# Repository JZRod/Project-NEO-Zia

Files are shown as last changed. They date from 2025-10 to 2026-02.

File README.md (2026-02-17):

# Project NEO Zia
This circut board is intended to make the New Mexico Zia out of LED's 
There is a [PDF](assets/README.pdf) version of this doccument in the assets folder
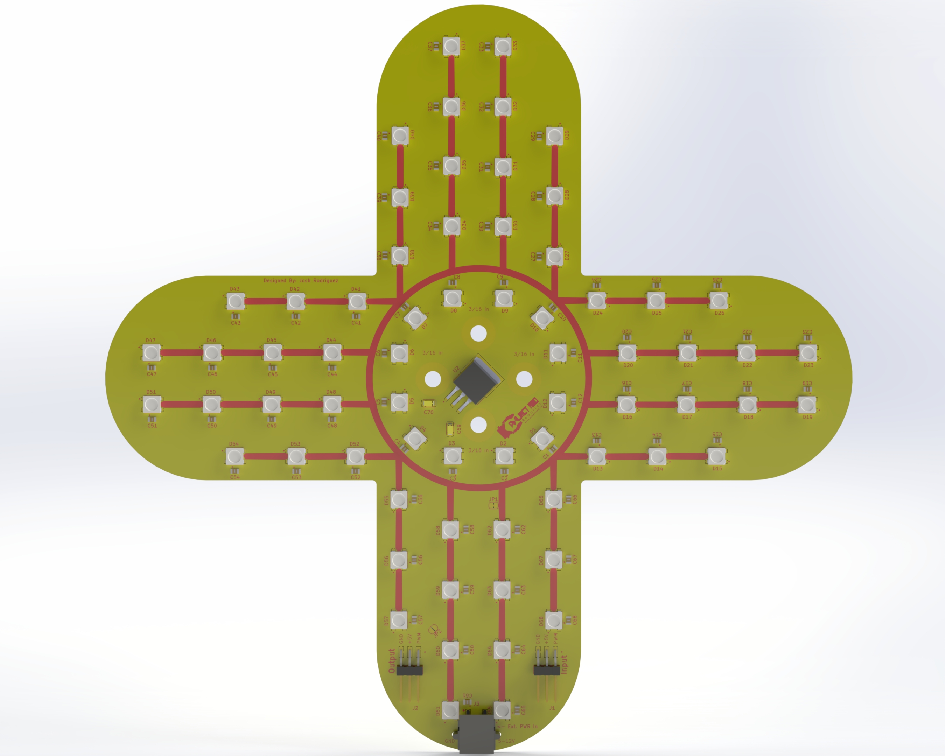
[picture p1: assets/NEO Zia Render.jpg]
ZIA PCB

## Using the board
This section goes over information on how to configure, wire, and mount the board. 
### Configuration
This PCB is designed to accept power from an external 12 volt input. It is also able to recieve power from a 5 volt PWM cable. By default the board is configured to recieve power from the 12 volt external power input.  
- For the PWM power input open JP1 and bridge JP2
- For external power input open JP2 and bridge JP1  
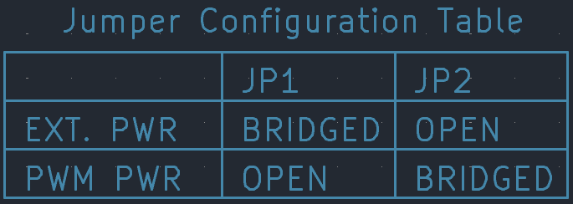
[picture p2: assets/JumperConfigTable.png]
configtable

> **NEVER BRIDGE BOTH JUMPERS AT ONCE**
### Wiring
#### External Power Input
The external power input can accept voltages between 5 and 12 volts. When using the external power input fuse it at a maximum of 5 amps.  
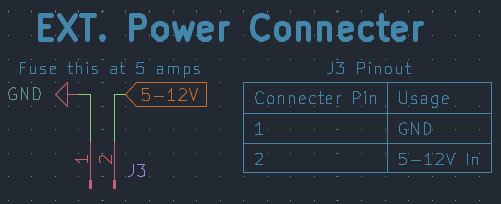
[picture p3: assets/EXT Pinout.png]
EXTPWRPINOUT

#### PWM Connections
There are two PWM connections on the board. One is a PWM output and one is an input. The output connector outputs a PWM signal after it has passed through all LED's. If you want to power the board with the PWM connection refer to the configuration section of this doccument.  
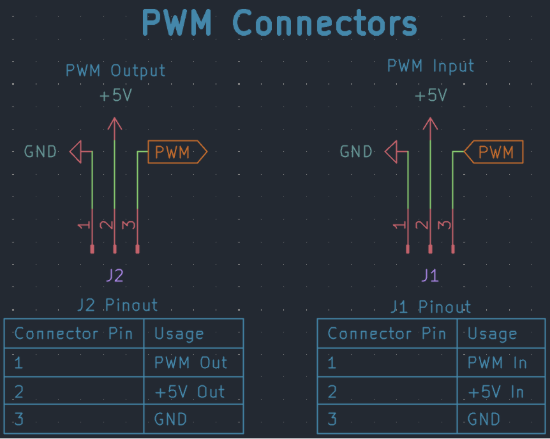
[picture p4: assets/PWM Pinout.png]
PWMPINOUT

>- The PWM output connector outputs whatever voltage it is provided through the PWM input  
>- The PWM output **does not touch the voltage regulator on the board at all**  
>- The pinout of these connectors is also labeled on the board  
### Programming
This board uses a standard NeoPixel PWM signal. The PWM output connector is connected to the DATA OUT pin on the last NeoPixel in the chain. The PWM input connector is connected to the DATA IN pin on the first NeoPixel in the chain. 
> The DATA IN/OUT pins do not have any protection on them  
>   The pinout for the PWM In/Out connecters can be seen in the Wiring section of this document
More information about these NeoPixels can be found in their [datasheet](https://cdn-shop.adafruit.com/product-files/1655/SKC6812RV__12VOP0274E_REV.A1_EN%2812%29.pdf)
#### NeoPixel Layout
The drawing below shous the pattern in which the NeoPixels are wired  
The PWM Input is connected to D68 and goes to each NeoPixel in a decreasing order. When the signal reaches D1 it is connected to the PWM Output connector.  
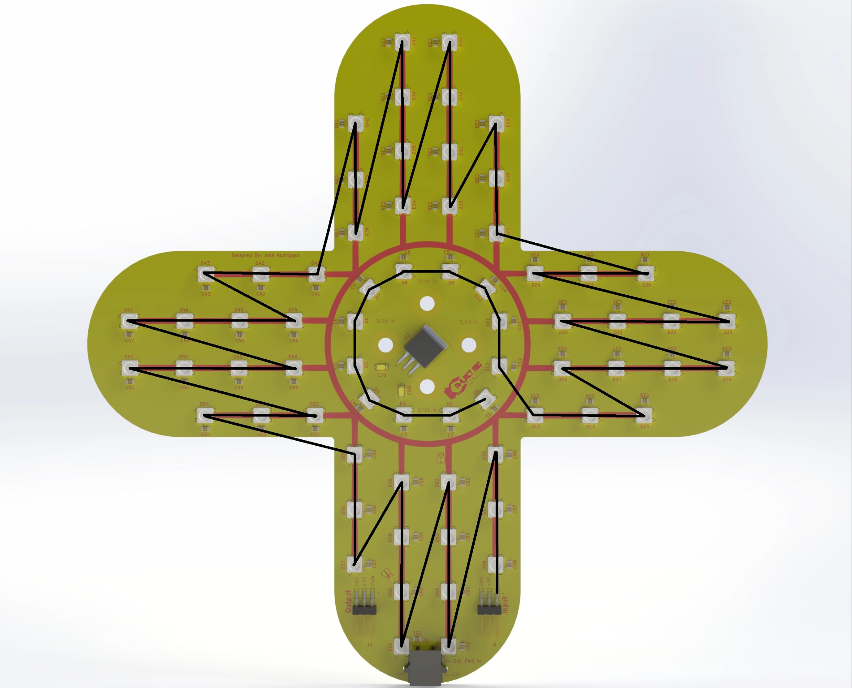
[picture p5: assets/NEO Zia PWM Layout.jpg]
NEOZIAPWMLayout

The black line starts at D68 and goes around the board in the same way the PWM signal is routed until it reaches D1.
> The DATA Out pin of D1 is wired to Pin 3 of the PWM Output Connector
### Mounting
On the newest revisions the 4 center holes are 3/16 and sized for 10/24 screws. Each revision has a STEP file in it's folder.  
> For all revisions, I would suggest that you check the mounting hole spacing and size in the CAD model
## Manufacturing
If you want to make this board you can either use the pre-made gerber files or customize them using the KiCad project files. All these files are available in the revision folders. The latest version can also be found on the releases page.
### Pre-Made Gerbers
In each revision folder there are zip files. These are the Gerber's, and you should be able to drop them straight in you PCB manufacturing service.  
> Some PCB manufacturing services will accept the bare KiCad PCB file.   
>**Read the REVISION NOTES.txt for info on what changed between each revision** 
### Customization  
If you want to customize this board each revision folder has a KiCad project file, a KiCad PCB File, and a KiCad Schematic file. 
> I suggest you use KiCad 9 or higher.  
>**Read the [REVISION NOTES.txt](Revisions/REVISION$20NOTES.txt) for info on what changed between each revision**  
## Credit  
**Designed by Josh Rodriguez for FIRST Robotics Competition Team 1164 Project NEO**

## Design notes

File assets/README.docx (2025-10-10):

# Project NEO Zia

This circuit board is intended to make the New Mexico Zia out of LED's

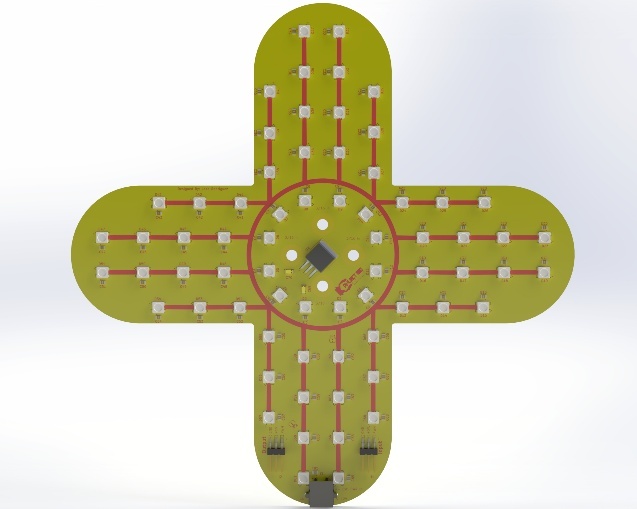
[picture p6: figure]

# Using the board

This section goes over information on how to configure, wire, and mount the board.

## Configuration

This PCB is designed to accept power from an external 12-volt input. It is also able to receive power from a 5-volt PWM cable. By default, the board is configured to receive power from the 12-volt external power input.

- For the PWM power input open JP1 and bridge JP2
- For external power input open JP2 and bridge JP1

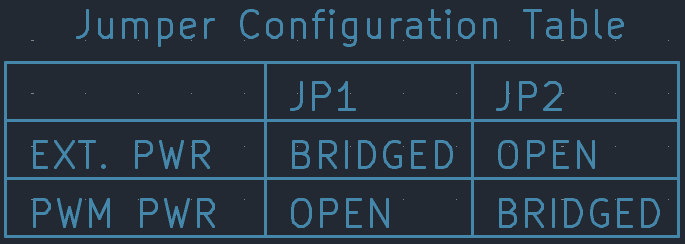
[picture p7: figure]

NEVER BRIDGE BOTH JUMPERS AT ONCE

## Wiring

### External Power Input

The external power input can accept voltages between 5 and 12 volts. When using the external power input fuse, it at a maximum of 5 amps.


### PWM Connections

There are two PWM connections on the board. One is a PWM output, and one is an input. The output connector outputs a PWM signal after it has passed through all LEDs. If you want to power the board with the PWM connection refer to the configuration section of this document.

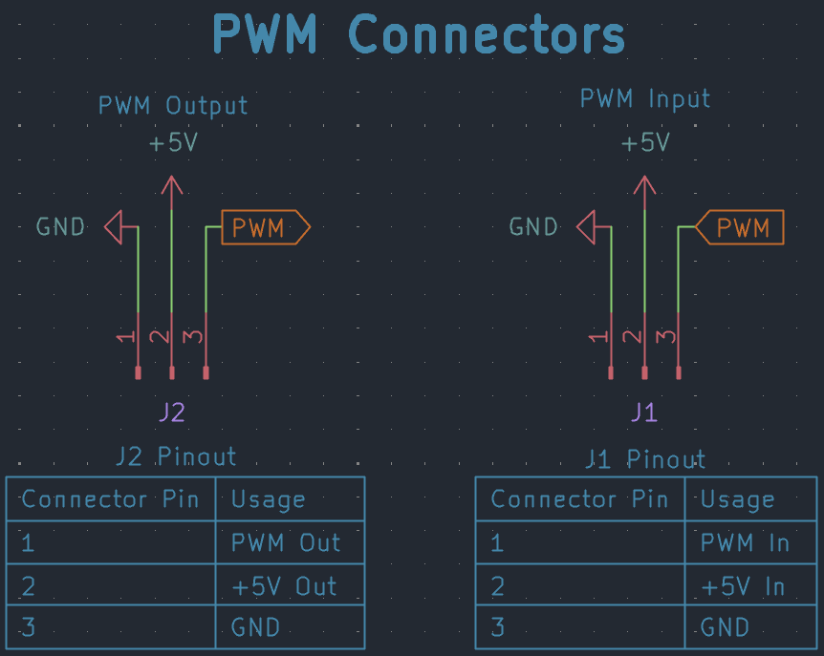
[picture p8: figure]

- The PWM output connector outputs whatever voltage it is provided through the PWM input
- The PWM output **does not touch the voltage regulator on the board at all**
- The pinout of these connectors is also labeled on the board

### Mounting

On the newest revisions the 4 center holes are 3/16 and sized for 10/24 screws. Each revision has a STEP file in its folder.

For all revisions, I would suggest that you check the mounting hole spacing and size in the CAD model

# Manufacturing

If you want to make this board, you can either use the pre-made Gerber files or customize them using the KiCad project files. All these files are available in the revision folders. The latest version can also be found on the releases page.

## Pre-Made Gerbers

In each revision folder there are zip files. These are the Gerber’s, and you should be able to drop them straight in you PCB manufacturing service.

Some PCB manufacturing services will accept the bare KiCad PCB file.

Read the REVISION NOTES.txt for info on what changed between each revision

## Customization

If you want to customize this board each revision folder has a KiCad project file, a KiCad PCB File, and a KiCad Schematic file.

I suggest you use KiCad 9 or higher.

Read the REVISION NOTES.txt for info on what changed between each revision

# Credit

If you customize your board, please leave the designer’s name and a link to the github repo on the board

Designed by Josh Rodriguez for FIRST Robotics Competition Team 1164 Project NEO

GitHub Repository: https://github.com/JZRod/Project-NEO-Zia

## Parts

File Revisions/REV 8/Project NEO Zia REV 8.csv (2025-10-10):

Id | Designator | Footprint | Quantity | Designation | Supplier and ref
1 | D53,D30,D32,D12,D51,D58,D21,D5,D4,D33,D39,D1,D35,D29,D68,D63,D2,D54,D36,D46,D15,D52,D38,D40,D62,D65,D67,D50,D60,D43,D44,D34,D25,D20,D66,D19,D49,D16,D45,D11,D37,D42,D8,D57,D6,D26,D7,D18,D48,D28,D14,D10,D9,D13,D22,D31,D61,D64,D17,D23,D27,D56,D24,D55,D3,D59,D47,D41 | LED_1655 | 68 | 1655 NeoPixel
2 | C43,C52,C6,C18,C7,C50,C40,C56,C33,C67,C11,C3,C23,C65,C59,C68,C32,C21,C44,C19,C61,C34,C49,C22,C55,C4,C15,C58,C45,C28,C31,C25,C66,C46,C26,C16,C27,C9,C42,C2,C64,C14,C53,C30,C60,C38,C54,C1,C35,C10,C29,C24,C36,C63,C12,C8,C62,C47,C37,C57,C41,C39,C51,C20,C17,C13,C5,C48 | CAPC220145_88N_KEM | 68 | C_Small
3 | C70,C69 | RESC3216X125N | 2 | C_Small
4 | J1,J2 | SAMTEC_TSM-103-02-L-SH-LC | 2 | TSM-103-02-L-SH-LC
5 | 3/16 in,3/16 in,3/16 in,3/16 in | 3-16in hole | 4 | 3/16 in
6 | U2 | TO254P1524X483-4N | 1 | LM1084IS-5.0_NOPB
7 | J3 | 691709710302 | 1 | Conn_01x02

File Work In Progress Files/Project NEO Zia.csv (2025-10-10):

Reference | Qty | Value | DNP | Exclude from BOM | Exclude from Board | Footprint | Datasheet
C1,C2,C3,C4,C5,C6,C7,C8,C9,C10,C11,C12,C13,C14,C15,C16,C17,C18,C19,C20,C21,C22,C23,C24,C25,C26,C27,C28,C29,C30,C31,C32,C33,C34,C35,C36,C37,C38,C39,C40,C41,C42,C43,C44,C45,C46,C47,C48 | 48 | C_Small |  |  |  | CustomParts:CAPC220145_88N_KEM | ~
D1,D2,D3,D4,D5,D6,D7,D8,D9,D10,D11,D12,D13,D14,D15,D16,D17,D18,D19,D20,D21,D22,D23,D24,D25,D26,D27,D28,D29,D30,D31,D32,D33,D34,D35,D36,D37,D38,D39,D40,D41,D42,D43,D44,D45,D46,D47,D48 | 48 | 1655 NeoPixel |  |  |  | CustomParts:LED_1655
J1,J2 | 2 | TSM-103-02-X-SH |  |  |  | TSM-103-02-X-SH:SAMTEC_TSM-103-02-X-SH

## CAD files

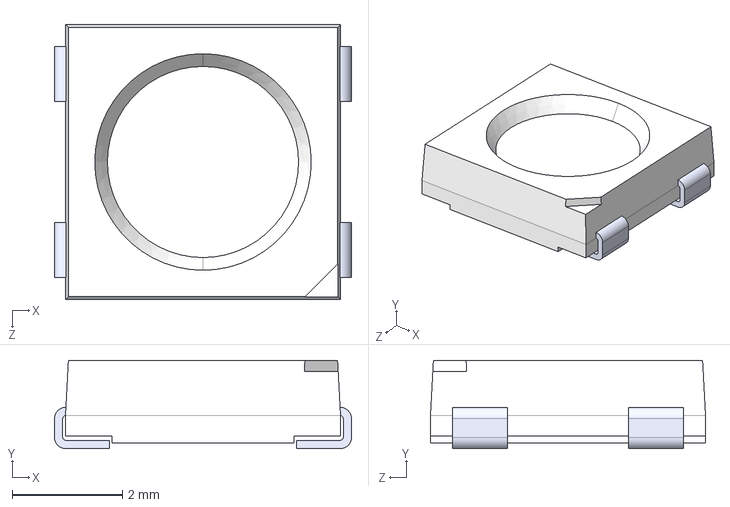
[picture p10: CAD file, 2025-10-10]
Custom Part Files/1655/1655.step
5.40 x 1.60 x 5.00 mm

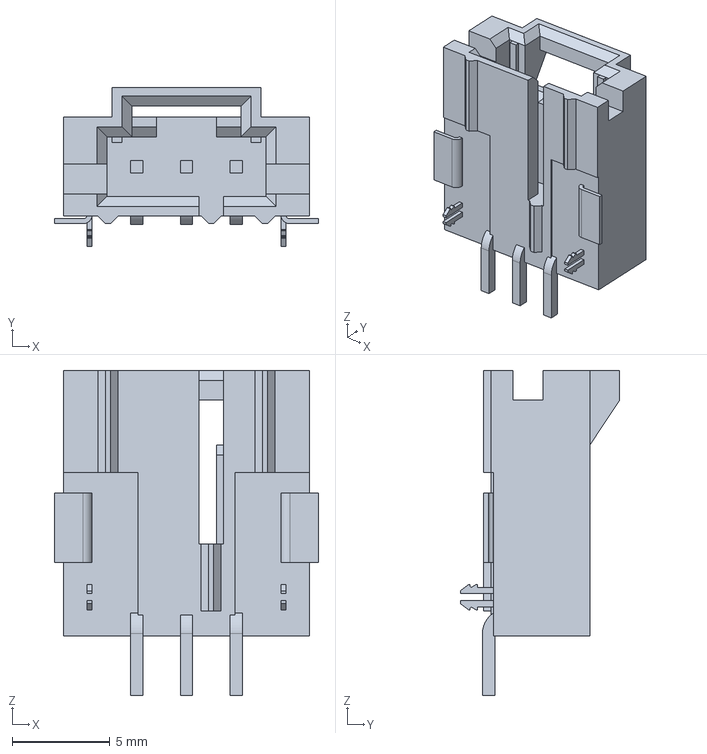
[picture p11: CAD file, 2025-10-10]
Custom Part Files/5_147278_2 (3)/KiCADv6/5-147278-2.stp
13.5 x 8.16 x 16.6 mm

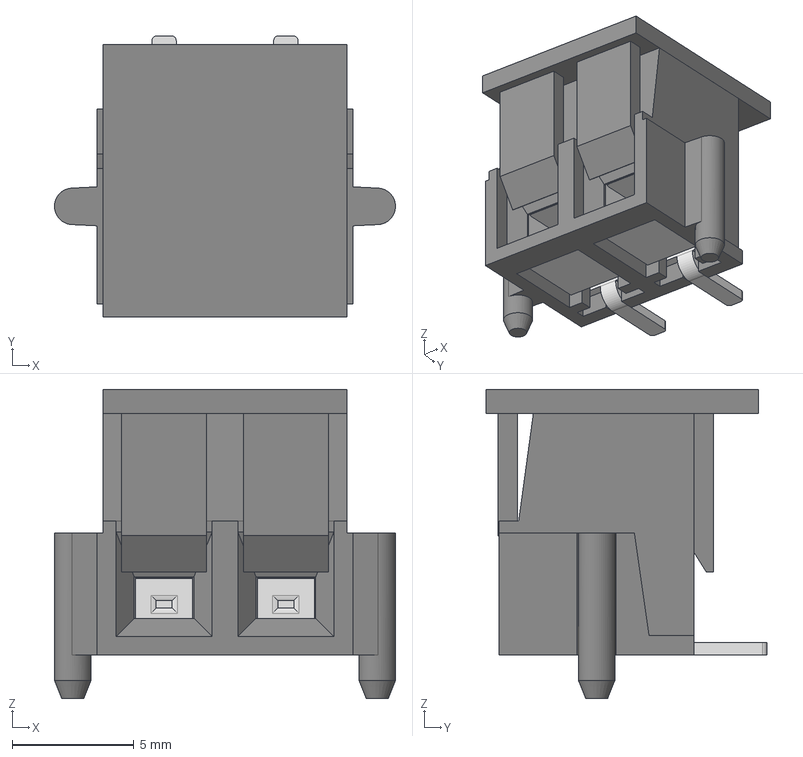
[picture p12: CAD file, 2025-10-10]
Custom Part Files/691709710302/Download_STP_691709710302_rev1.stp
14.0 x 11.5 x 12.7 mm
6917097103xx_CAGE x 2
6917097103xx_PIN x 2
6917097103xx_VIS x 2
6917097103xx_PAD

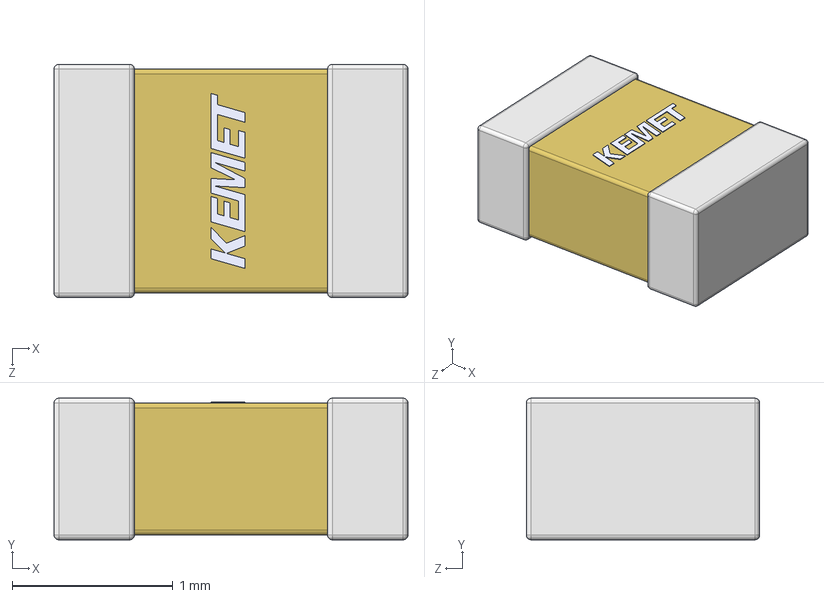
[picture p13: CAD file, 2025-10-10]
Custom Part Files/C0805C104Z4VACTU/KiCADv6/C0805C104Z4VAC7800.step
2.20 x 0.88 x 1.45 mm

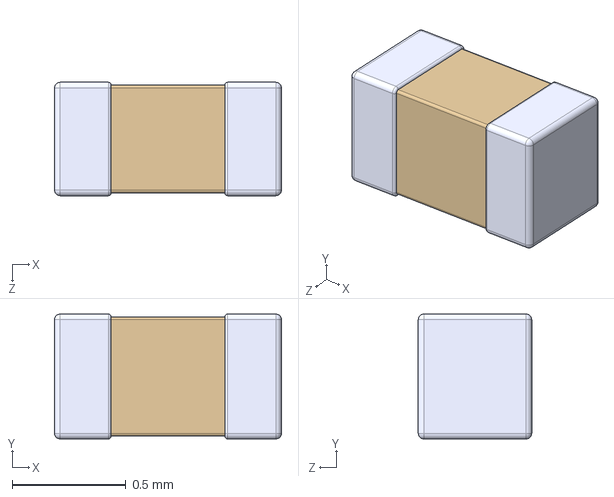
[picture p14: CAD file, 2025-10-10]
Custom Part Files/CL05B104KO5NNNC (1)/CL05B104KO5NNNC.step
1.00 x 0.55 x 0.5 mm

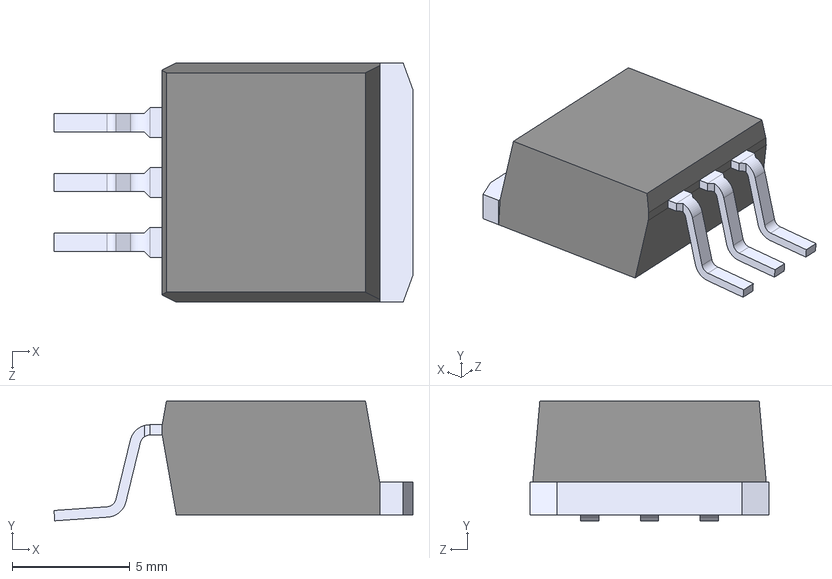
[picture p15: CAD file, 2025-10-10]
Custom Part Files/LM1084IS_5_0_NOPB/LM1084IS-5.0_NOPB.step
15.2 x 5.08 x 10.2 mm

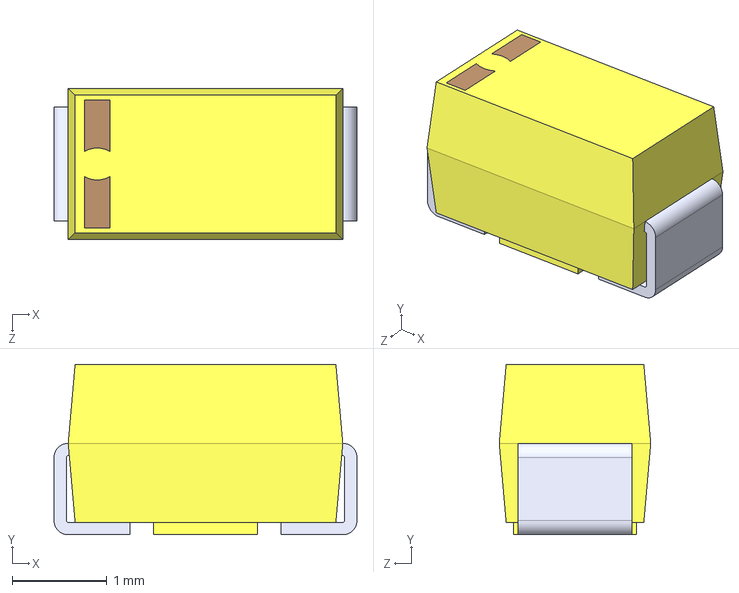
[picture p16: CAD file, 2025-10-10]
Custom Part Files/T491A106M016AT (1)/T491A106M016AT.step
3.20 x 1.80 x 1.60 mm

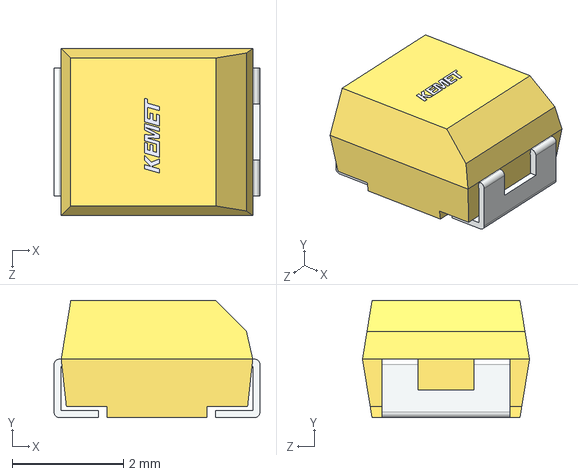
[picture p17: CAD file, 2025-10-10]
Custom Part Files/T498B106K006ATE2K1/CTSM_TCM2NK_3528_L3.7W3H2.1T0.13S0.8F2.3A1.9B0.55E2.2G1.8P0.5R1X0.2.step
3.70 x 2.11 x 3.00 mm

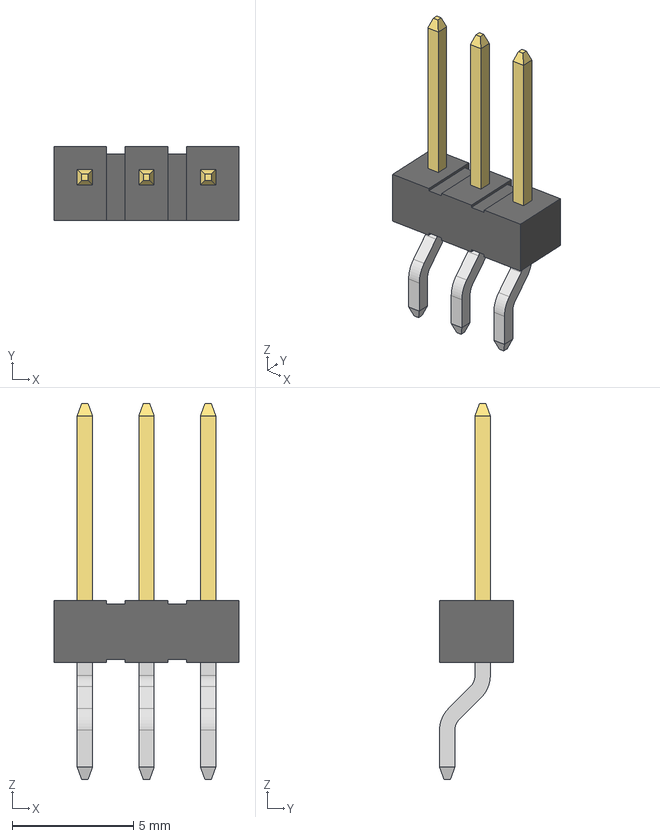
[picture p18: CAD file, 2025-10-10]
Custom Part Files/TSM_103_02_L_SH/TSM-103-02-X-SH.step
7.62 x 3.05 x 15.5 mm
TSM-103-02-SH_body
T-1S6-15-L(-02-3-SH)
T-1S6-15-L(-02-3-SH)2

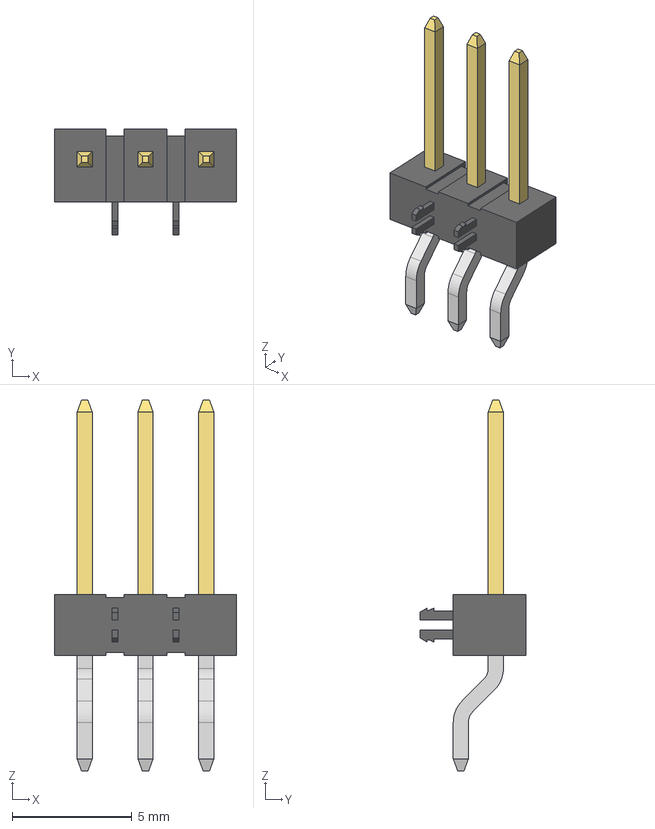
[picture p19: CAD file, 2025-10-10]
Custom Part Files/TSM_103_02_L_SH_LC/TSM-103-02-L-SH-LC.step
7.62 x 4.44 x 15.5 mm
TSM-103-02-SH-LC_body
T-1S6-15-L(-02-3-SH)
T-1S6-15-L(-02-3-SH)2

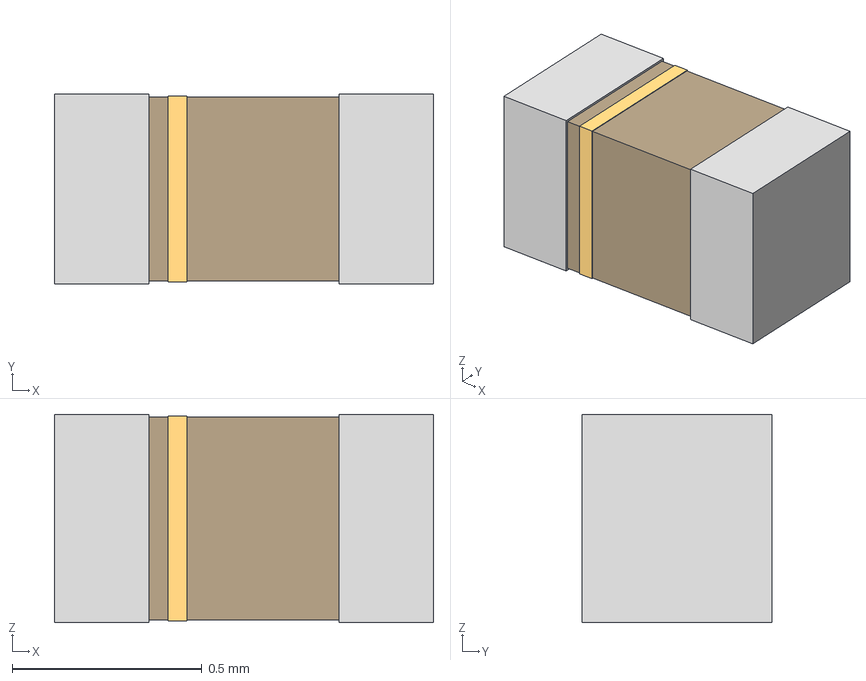
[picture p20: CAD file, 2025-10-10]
Custom Part Files/CL05B104KO5NNNC (1)/CAP_CL05_SAM.step
1.00 x 0.5 x 0.55 mm

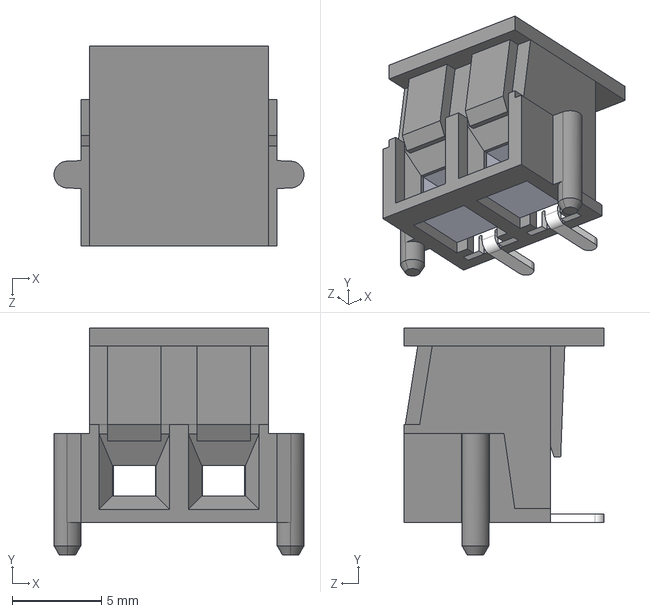
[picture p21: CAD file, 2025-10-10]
Custom Part Files/691709710302/691709710302.step
14.0 x 12.7 x 11.2 mm

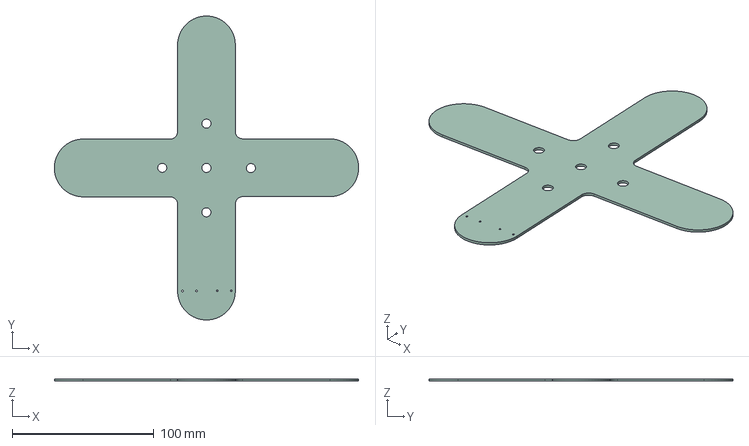
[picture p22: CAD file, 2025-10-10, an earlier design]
Revisions/REV 1.5/Project NEO Zia REV 1_5.step
214.8 x 214.6 x 1.51 mm

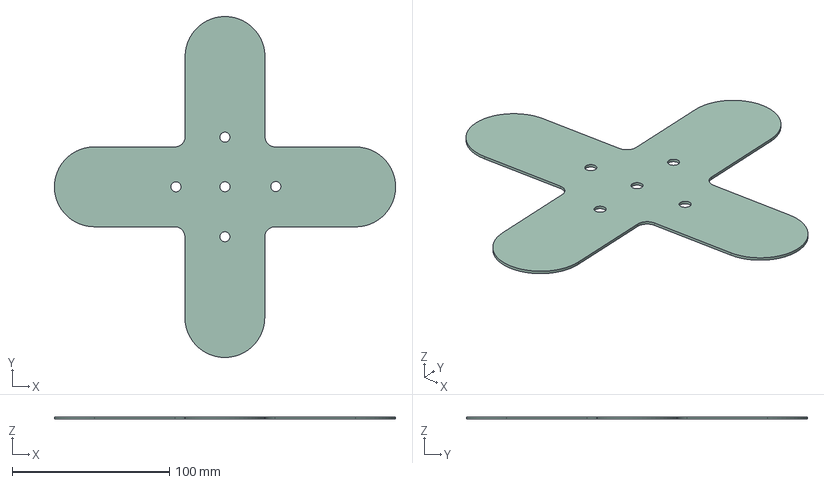
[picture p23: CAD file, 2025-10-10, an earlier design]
Revisions/REV 2/Project NEO Zia REV 2.step
216.9 x 216.8 x 1.51 mm

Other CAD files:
Revisions/REV 1/Project NEO Zia REV 1.step
Revisions/REV 3/Project NEO Zia REV 3.step
Revisions/REV 4/Project NEO Zia REV 4.step
Revisions/REV 5/Project NEO Zia REV 5.step
Revisions/REV 6/Project NEO Zia REV 6.step
Revisions/REV 7.5.1/Project NEO Zia.step
Revisions/REV 7.5.2/Project NEO Zia.step
Revisions/REV 7/Project NEO Zia.step

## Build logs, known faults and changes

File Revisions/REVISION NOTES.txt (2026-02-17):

 ________________________________________________________________        ________________________
|Key:								                             |      |Reading REV #'s         |
|REV# (Revision Number)- (Completion date, Month/Day/Year)       |      |        REV x.x         |
|- Notes describing changes go here.				             |      |            ^ ^         |
|- Parts always start with the brand then the part number.       |      |            | |         |
|	# Adafruit (Brand) 1655 (Part Number)			             |      | Major Change |         |
|# Any Comments made on the revision                             |      |         Minor Change   |
|	# Comments for a specific item go under the item             |      |________________________|
|# Extra info that might be helpful is at the bottom of document |
|________________________________________________________________|

Original REV's - 4/19/2025 through 5/12/2025
# What is left of Original Project files before drive D:\ died.
# Contained original Schematic, Project, and PCB files. (Only .kicad_pcb file was left)
- Added Adafruit 1655 NeoPixel
- Added Samsung Electro-Mechanics CL05B104KO5NNNC
- Added footprint/symbol's for Adafruit 1655 and Samsung Electro-Mechanics CL05B104KO5NNNC

REV 1 - 5/16/2025
# Recreation of Original Project using original .kicad_pcb file
- Added Samtec Inc. TSM-103-02-X-SH in place of right angle pin header (No part #, used built in KiCad footprint & symbol)

REV 1.5 - 5/17/2025
- Replaced Samtec Inc. TSM-103-02-X-SH with TE Connectivity 5-147278-2

REV 2 - 5/17/2025
# Built off of REV 1 instead of REV 1.5
- Widened Fingers from 1 inch to 2 inches
- Added notes on User.Comments and User.Drawings layers
- No Schematic Changes

REV 3 - 5/19/2025
- Replaced Samsung Electro-Mechanics CL05B104KO5NNNC with KEMENT C0805C104M4RACTU
- Rerouted power tracks along center ring of LED's to accommodate new capacitors

REV 4 - 5/20/2025
- Replaced Samtec Inc. TSM-103-02-X-SH with Samtec Inc. TSM-103-02-X-SH-LC
- Changed board thickness to .7mm
	# This was done to accommodate board lock feature on the Samtec Inc. TSM-103-02-X-SH-LC connector.

REV 5 - 5/26/2025
- Added Project NEO logo to back side of board

REV 6 - 6/17/2025 - 9/10/2025
#6/17/2025
- Added extra row of LED's to each finger
	# The extra row was added so the ZIA represents the Zia on the NM Flag
	# Old Zia Revisions only had 3 prongs instead of 4
# Schematic Only no PCB File!!

# Worked on 9/10/25
- Updated PCB File
- Changed 1/4 in holes to 3/16 in

REV 7 - 9/19/25
- Moved Project NEO Logo to front of board
- Added designer name to front of board
- Added external power input through Würth Elektronik 1297-1108-6-ND screw terminal
	- Uses Texas Instruments LM1084IS-5.0/NOPB voltage regulator to output 5 volts to NeoPixel's
		# Accepts voltages from 5 to 12 volts
		# does not touch PWM connectors except for input power
			# Has to be configured using JP1 and JP2
- Added New Mexico Zia illustration to F.UVPrint
	# Replaced User.1 and User.2 layers with F.UVPrint and B.UVPrint

REV 7.5.1 - 10/7/25
- Merged F.Silkscreen to F.UVPrint
	# Using modified footprints with silkscreen on F.UVPrint layer
- Fixed weird issue with capacitors duplicating when using Update Footprints tool in PCB editor
- Added label to external power input

REV 7.5.2 - 10/7/25
- Merged F.Silkscreen to F.UVPrint
	# All silkscreens/illustrations are on F.Silkscreen
# Everything else is the same as REV 7.5.1
- Added "For more info visit: https://github.com/JZRod/Project-NEO-Zia" to all versions
	# backported to all pre-existing versions
- Fixed voltage regulator tab being shorted to GND
	# Backported to all relevant rev's

REV 8 - 2/13/26
- Added 5V copper plane in center for TI LM1084 voltage regulator
- Rearranged filter capacitors for voltage regulator and some NeoPixel's
- Added REV marker to board
	# On Rear Silkscreen
- Added Jumper Config. Table
	# On Rear Silkscreen
- Moved Designer name to rear silkscreen
 _________________________________________________________________________________________________
|Extra Info:                                                                                      |
|- .kicad_pcb refers to the KiCad PCB file                                                        |
|- .kicad_sch refers to the KiCad Schematic file                                                  |
|- .kicad_pro refers to the Kicad Project file                                                    |
|# If a Revision Folder has both a PCB and Schematic File KiCad will auto generate a project file |
|	# This is not on purpose it just happens when both file types are together                    |
|- User.Comments and User.Drawings both refer to both the note layers in the PCB editor		      |
|- F.UVPrint and B.UVPrint (Added in REV 7) are intended for UV Print drawings			          |
|	# Can also be a render for use by PCBWay						                              |
|       # Are being phased out as of REV 8							                              |
|_________________________________________________________________________________________________|

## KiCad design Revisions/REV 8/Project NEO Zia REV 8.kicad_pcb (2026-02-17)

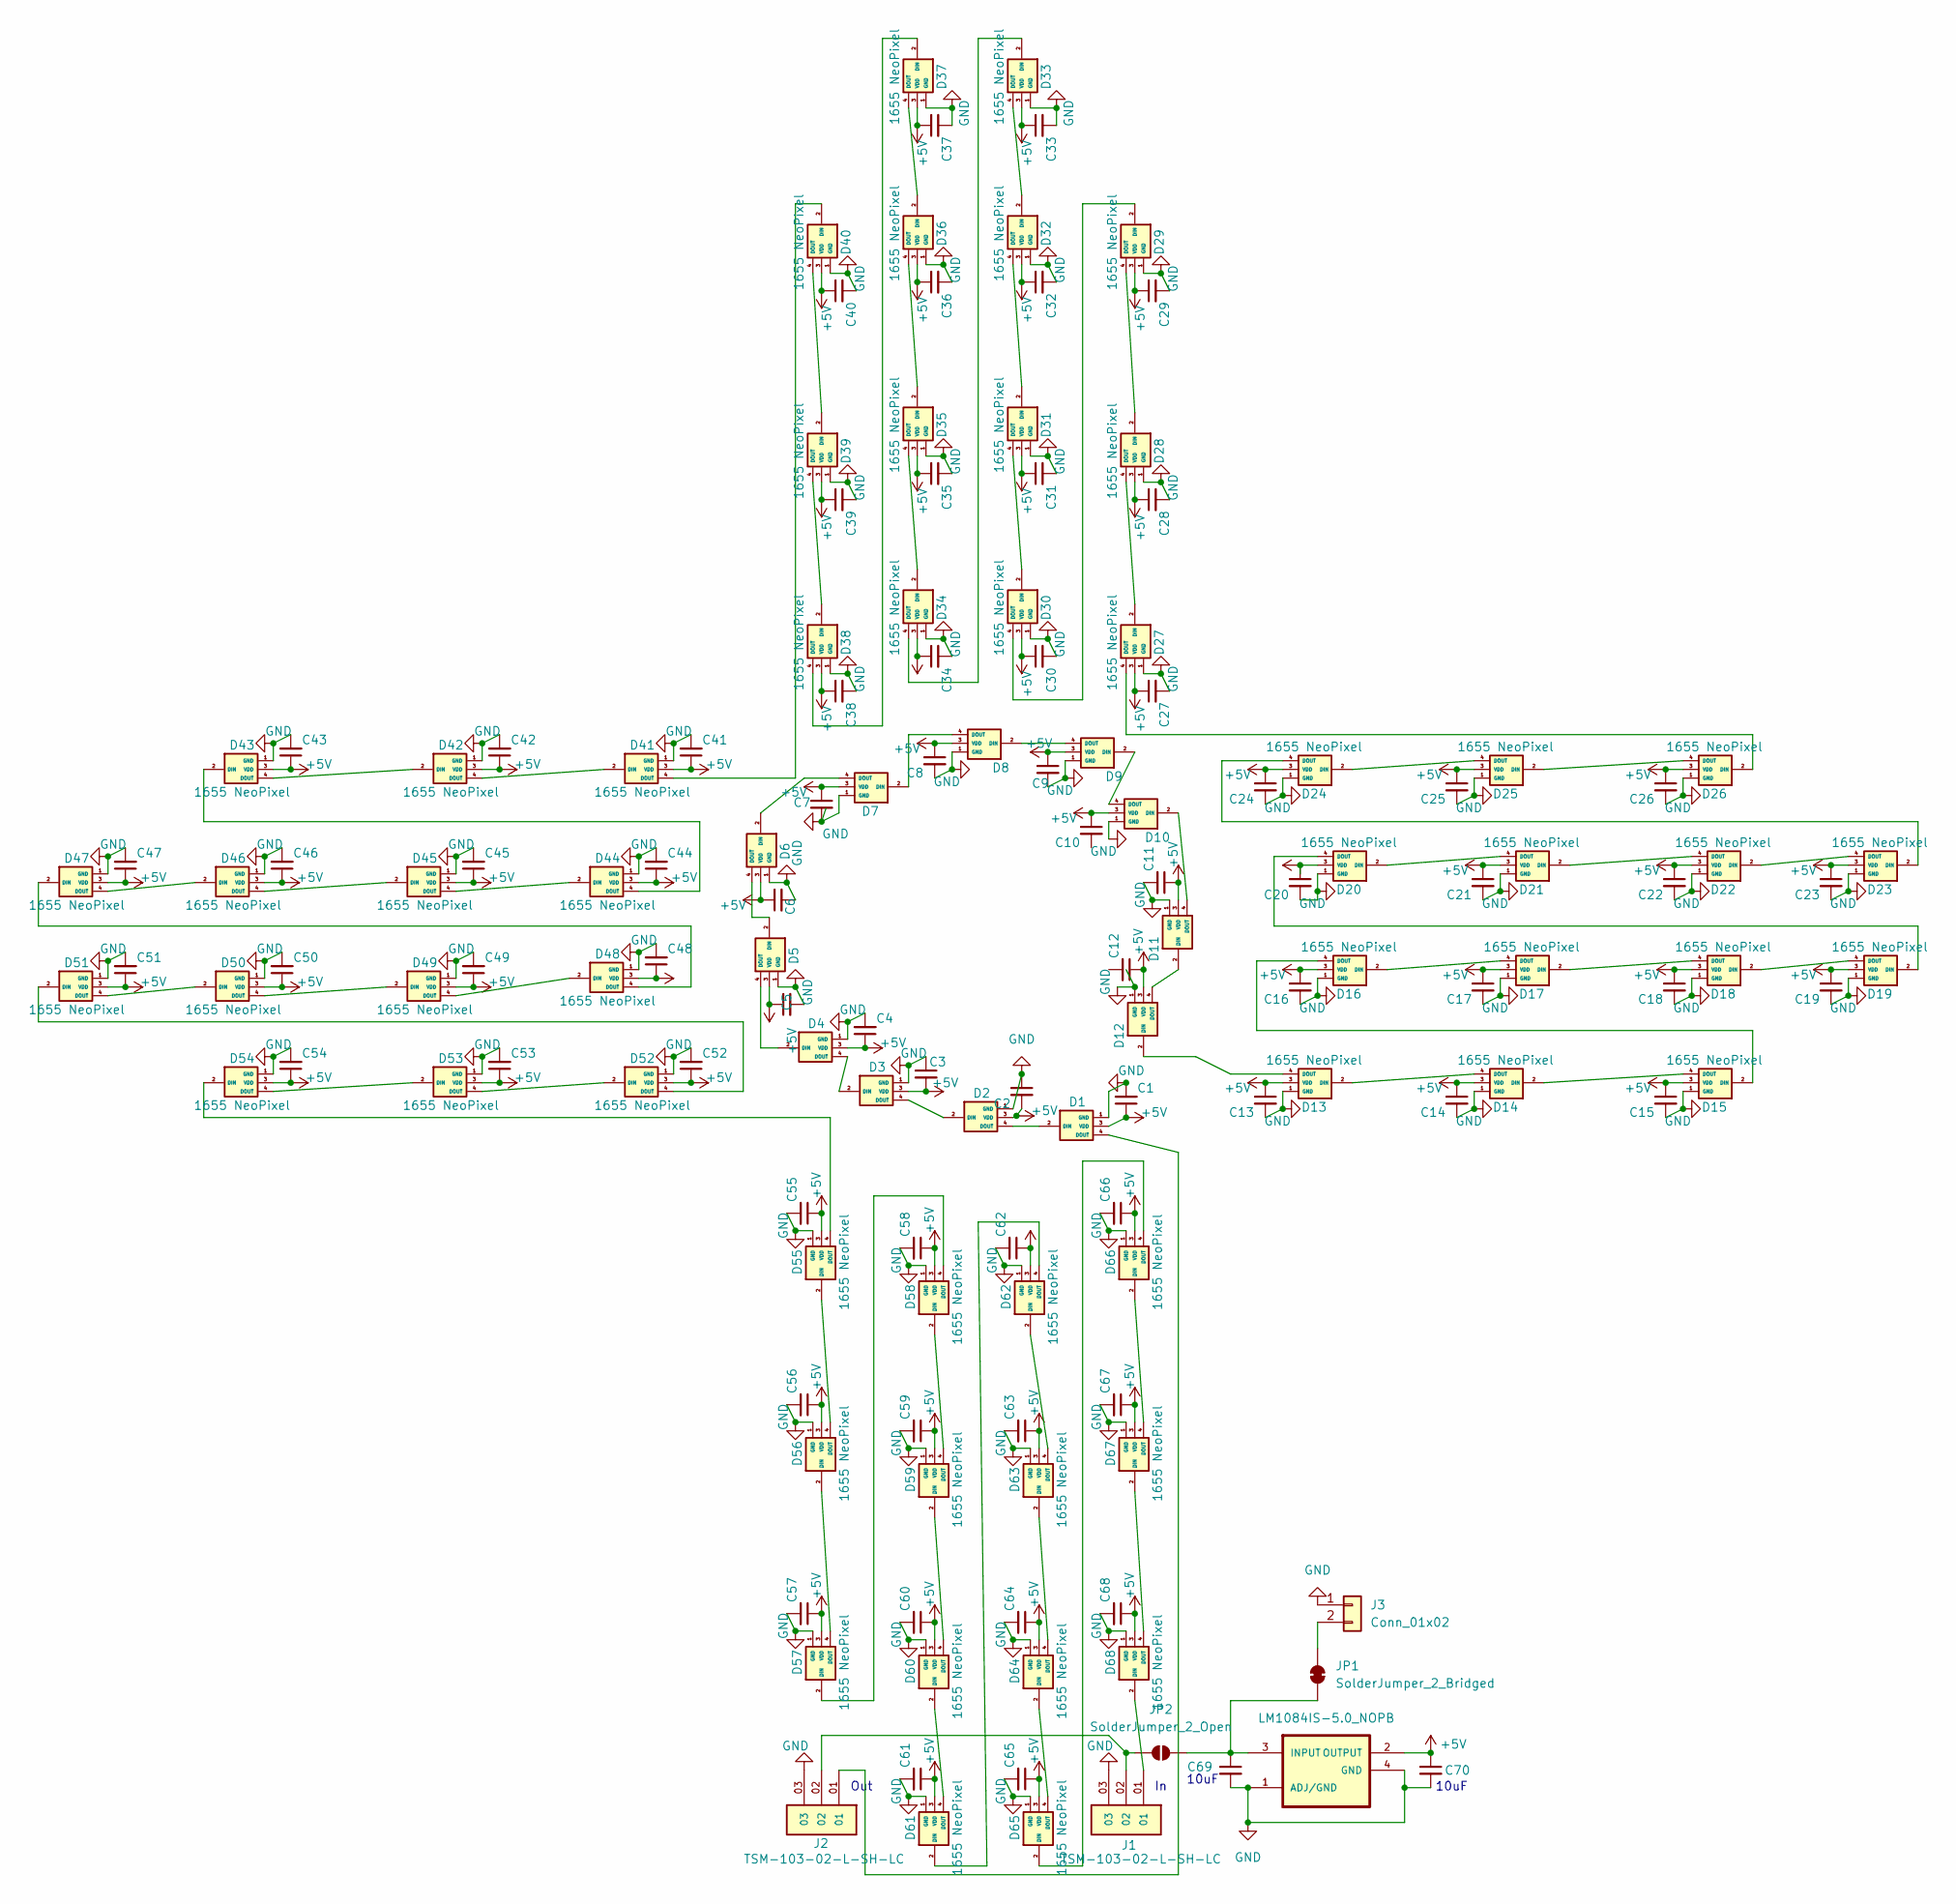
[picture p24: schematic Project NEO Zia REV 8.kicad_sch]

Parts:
C1, C2, C3, C4, C5, C6, C7, C8, C9, C10, C11, C12, C13, C14, C15, C16, C17, C18, C19, C20, C21, C22, C23, C24, C25, C26, C27, C28, C29, C30, C31, C32, C33, C34, C35, C36, C37, C38, C39, C40, C41, C42, C43, C44, C45, C46, C47, C48, C49, C50, C51, C52, C53, C54, C55, C56, C57, C58, C59, C60, C61, C62, C63, C64, C65, C66, C67, C68: C_Small; CAPC220145_88N_KEM
C69, C70: C_Small; RESC3216X125N
D1, D2, D3, D4, D5, D6, D7, D8, D9, D10, D11, D12, D13, D14, D15, D16, D17, D18, D19, D20, D21, D22, D23, D24, D25, D26, D27, D28, D29, D30, D31, D32, D33, D34, D35, D36, D37, D38, D39, D40, D41, D42, D43, D44, D45, D46, D47, D48, D49, D50, D51, D52, D53, D54, D55, D56, D57, D58, D59, D60, D61, D62, D63, D64, D65, D66, D67, D68: 1655 NeoPixel; LED_1655; PARTREV 01
J1, J2: TSM-103-02-L-SH-LC; SAMTEC_TSM-103-02-L-SH-LC; PARTREV R
J3: Conn_01x02; 691709710302
JP1: SolderJumper_2_Bridged; SolderJumper-2_P1.3mm_Bridged_RoundedPad1.0x1.5mm
JP2: SolderJumper_2_Open; SolderJumper-2_P1.3mm_Open_RoundedPad1.0x1.5mm
U2: LM1084IS-5.0_NOPB; TO254P1524X483-4N

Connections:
unnamed: D1.2 (DIN), D2.4 (DOUT)
unnamed: D1.4 (DOUT), J2.01
unnamed: D2.2 (DIN), D3.4 (DOUT)
unnamed: D3.2 (DIN), D4.4 (DOUT)
unnamed: D4.2 (DIN), D5.4 (DOUT)
unnamed: D5.2 (DIN), D6.4 (DOUT)
unnamed: D6.2 (DIN), D7.4 (DOUT)
unnamed: D7.2 (DIN), D8.4 (DOUT)
unnamed: D8.2 (DIN), D9.4 (DOUT)
unnamed: D10.2 (DIN), D11.4 (DOUT)
unnamed: D9.2 (DIN), D10.4 (DOUT)
unnamed: D11.2 (DIN), D12.4 (DOUT)
unnamed: D12.2 (DIN), D13.4 (DOUT)
unnamed: D13.2 (DIN), D14.4 (DOUT)
unnamed: D14.2 (DIN), D15.4 (DOUT)
unnamed: D15.2 (DIN), D16.4 (DOUT)
unnamed: D16.2 (DIN), D17.4 (DOUT)
unnamed: D17.2 (DIN), D18.4 (DOUT)
unnamed: D18.2 (DIN), D19.4 (DOUT)
unnamed: D19.2 (DIN), D20.4 (DOUT)
unnamed: D20.2 (DIN), D21.4 (DOUT)
unnamed: D21.2 (DIN), D22.4 (DOUT)
unnamed: D22.2 (DIN), D23.4 (DOUT)
unnamed: D23.2 (DIN), D24.4 (DOUT)
unnamed: D24.2 (DIN), D25.4 (DOUT)
unnamed: D25.2 (DIN), D26.4 (DOUT)
unnamed: D26.2 (DIN), D27.4 (DOUT)
unnamed: D27.2 (DIN), D28.4 (DOUT)
unnamed: D28.2 (DIN), D29.4 (DOUT)
unnamed: D29.2 (DIN), D30.4 (DOUT)
unnamed: D30.2 (DIN), D31.4 (DOUT)
unnamed: D31.2 (DIN), D32.4 (DOUT)
unnamed: D32.2 (DIN), D33.4 (DOUT)
unnamed: D33.2 (DIN), D34.4 (DOUT)
unnamed: D34.2 (DIN), D35.4 (DOUT)
unnamed: D35.2 (DIN), D36.4 (DOUT)
unnamed: D36.2 (DIN), D37.4 (DOUT)
unnamed: D37.2 (DIN), D38.4 (DOUT)
unnamed: D38.2 (DIN), D39.4 (DOUT)
unnamed: D39.2 (DIN), D40.4 (DOUT)
unnamed: D40.2 (DIN), D41.4 (DOUT)
unnamed: D41.2 (DIN), D42.4 (DOUT)
unnamed: D42.2 (DIN), D43.4 (DOUT)
unnamed: D43.2 (DIN), D44.4 (DOUT)
unnamed: D44.2 (DIN), D45.4 (DOUT)
unnamed: D45.2 (DIN), D46.4 (DOUT)
unnamed: D46.2 (DIN), D47.4 (DOUT)
unnamed: D47.2 (DIN), D48.4 (DOUT)
unnamed: D48.2 (DIN), D49.4 (DOUT)
unnamed: D49.2 (DIN), D50.4 (DOUT)
unnamed: D50.2 (DIN), D51.4 (DOUT)
unnamed: D51.2 (DIN), D52.4 (DOUT)
unnamed: D52.2 (DIN), D53.4 (DOUT)
unnamed: D53.2 (DIN), D54.4 (DOUT)
unnamed: D54.2 (DIN), D55.4 (DOUT)
unnamed: D55.2 (DIN), D56.4 (DOUT)
unnamed: D56.2 (DIN), D57.4 (DOUT)
unnamed: D57.2 (DIN), D58.4 (DOUT)
unnamed: D58.2 (DIN), D59.4 (DOUT)
unnamed: D59.2 (DIN), D60.4 (DOUT)
unnamed: D60.2 (DIN), D61.4 (DOUT)
unnamed: D61.2 (DIN), D62.4 (DOUT)
unnamed: D62.2 (DIN), D63.4 (DOUT)
unnamed: D63.2 (DIN), D64.4 (DOUT)
unnamed: D64.2 (DIN), D65.4 (DOUT)
unnamed: D65.2 (DIN), D66.4 (DOUT)
unnamed: D66.2 (DIN), D67.4 (DOUT)
unnamed: D67.2 (DIN), D68.4 (DOUT)
unnamed: D68.2 (DIN), J1.01
unnamed: J3.2, JP1.2 (B)
unnamed: C69.1, JP1.1 (A), JP2.1 (A), U2.3 (INPUT)
unnamed: J1.02, J2.02, JP2.2 (B)

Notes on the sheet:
10uF
Out

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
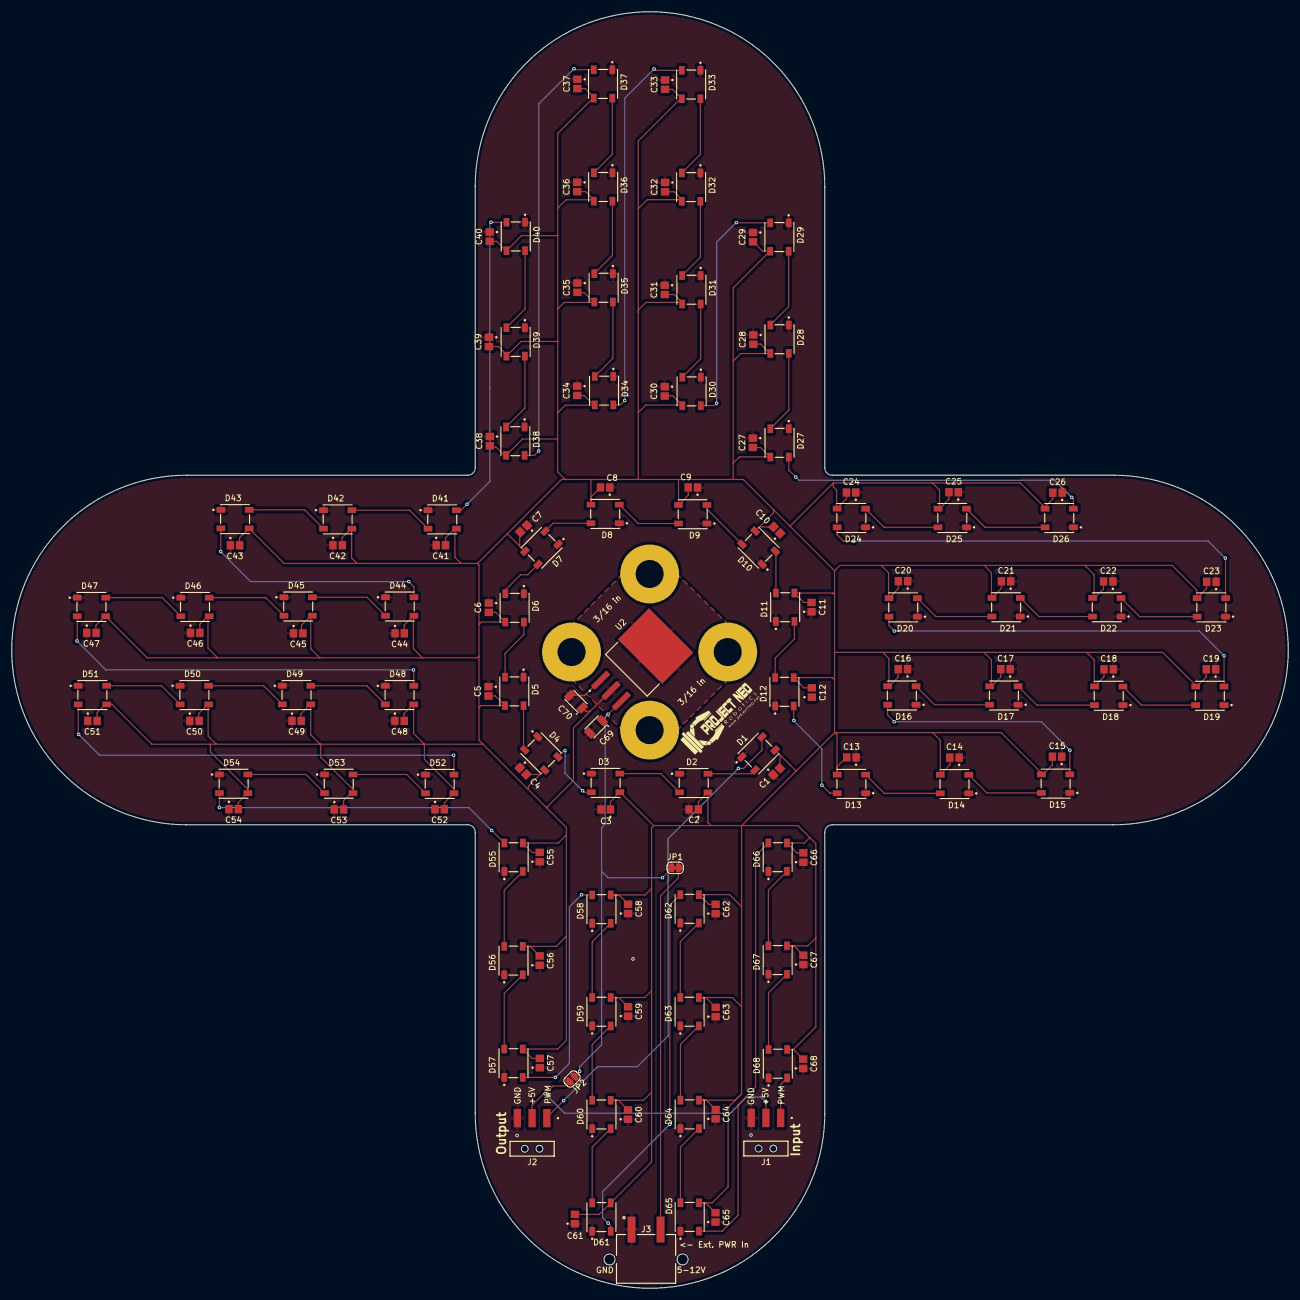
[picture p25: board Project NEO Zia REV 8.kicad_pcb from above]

Board: 2 copper layers, 220.2 x 220.2 mm, 148 parts (0 on the bottom side), 74 nets.

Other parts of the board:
3/16 in, 3/16 in#2, 3/16 in#3, 3/16 in#4: 3/16 in; 3-16in hole

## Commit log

2025-10-10 Added all custom parts and project files
    [1655.step, 5-147278-2.stp, 691709710302.step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]
2025-10-10 Updated REV 1 to have STEP file and Gerber zip
    [Project NEO Zia REV 1.kicad_pcb, Project NEO Zia REV 1.step]
2025-10-10 Added Gerber and STEP files Removed un-needed files Updated sheet information
    [Project NEO Zia REV 1_5.kicad_pcb, Project NEO Zia REV 1_5.kicad_sch, Project NEO Zia REV 1_5.step]
2025-10-10 - Added "For more info visit: https://github.com/JZRod/Project-NEO-Zia" to all versions # backported to all pre-existing versions - Fixed voltage regulator tab being shorted to GND # Backported to al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
    [Project NEO Zia Original.kicad_pcb, Project NEO Zia REV 1.csv, Project NEO Zia REV 1.kicad_pcb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]
2025-10-10 Moved all Work In Progress Files to Work In Progress folder
    [Project NEO Zia.csv, Project NEO Zia.kicad_pcb, Project NEO Zia.kicad_sch]
2025-10-14 Add files via upload
    Added image that shows how the board's PWM is routed
2025-10-14 Add files via upload
    Updated JumperConfigTable.png and PWM Pinout.png
2025-10-14 Updated PWM Pinout.png
2025-10-14 Updated PWM Pinout.png for the 3rd time
2025-10-14 Updated PWM Pinout.png
    Hopefully for the last time today
2025-10-14 Updated PWM Pinout.png
    i think it will work this time
2025-10-14 Updated PWM Pinout.png
    I was wrong it was not the last time I would updated this
2026-02-17 - Added 5V copper plane in center for TI LM1084 voltage regulator - Rearranged filter capacitors for voltage regulator and some NeoPixel's - Added REV marker to board # On Rear Silkscreen - Added Jum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
    [Project NEO Zia REV 8.csv, Project NEO Zia REV 8.kicad_pcb, Project NEO Zia REV 8.kicad_sch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]

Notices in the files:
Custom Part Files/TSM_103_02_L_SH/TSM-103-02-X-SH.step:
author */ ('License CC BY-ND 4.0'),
